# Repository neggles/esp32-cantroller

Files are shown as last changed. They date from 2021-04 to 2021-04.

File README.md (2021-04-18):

# EltekController


This is a little board I whipped up to connect to my [Eltek Flatpack2 Breakout Board](https://github.com/neg2led/EltekFlatpack2) but it should be useful as a general CANBUS control board with wide voltage input.

Most of the parts on the board are outfitted with their LCSC code for KiKit's JLCPCB SMT fab autogeneration. 

I'm using an ESP32-S2-WROOM / ESP32-S2-WROVER module, abusing the on-board USB DFU to avoid having a USB-UART IC.

There's a header designed to take a cheap AliExpress 1.3" 128x64 OLED module, a Qwiic connector for... reasons? and a footprint that matches ESP-Prog pinout and works with:

- Any 2x3 1.27mm IDC header, shrouded or unshrouded, or appropriate pogopin matrix
- Tag-Connect TC2030-NL programming pogopin connector
- Harwin Gecko 1.25mm pitch wire-to-board connector

There's probably some other stuff that'll fit just fine as well.

The DC-DC converter module is a fancy TDK-Lambda one which I got a whole bunch of from Digikey's Chip Outpost for like 20c each, when I run out I'll probably make another version using either an on-board converter or another module, one that outputs 5V so the Qwiic connector is actually in-spec and the XC6220 isn't solely used for USB-bus-powered mode.

To be honest, expect to see the on-board DC-DC version soon, because this module is C H O N K Y.

I've probably made some really bad design choices here, please don't judge me.

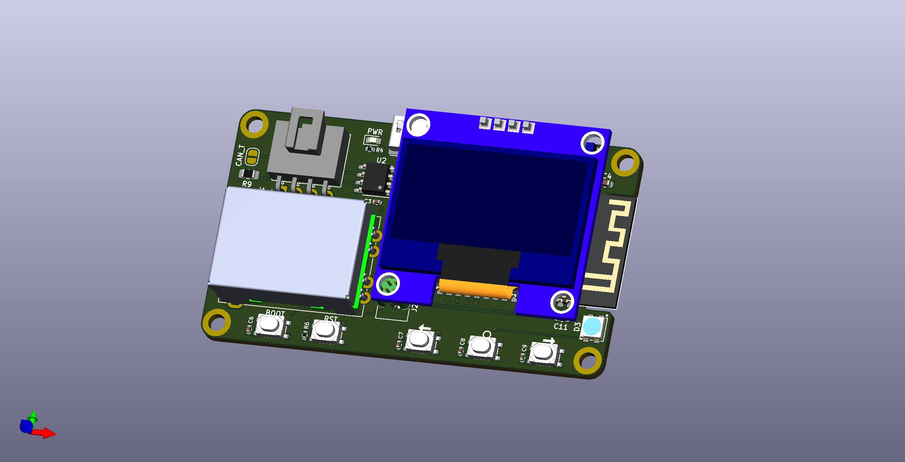
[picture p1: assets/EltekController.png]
KiCad raytraced board render


## Repository Structure
- `EltekController` contains the main schematics and board drawing
- `EltekController/EltekController.pretty` contains the board-specific footprints
- `EltekController/shapes3D` contains the 3D models for parts on the board (and a bunch of extras from my various experiments)

## Building
Simply call `make` in the top-top level directory. The `build` directory will then contain:

- the main board
- A panelized version of said board
- zipped gerbers for the boards you can directly use for manufacturing
- zipped gerbers and SMT assembly BOM/position files for JLCPCB's SMT assembly service for the single-board version.

Makefile uses [Jan Mrázek](https://github.com/yaqwsx)'s [KiKit](https://github.com/yaqwsx/KiKit), which I cannot recommend enough, and therefore has to be available on your system.

Jan's [jlcparts](https://yaqwsx.github.io/jlcparts/) app was also extremely useful in narrowing down part choices based on what JLCPCB have available.

-----
### **IMPORTANT NOTE:** If you give JLCPCB these files as-is, *please* verify the orientation of every part before submitting.

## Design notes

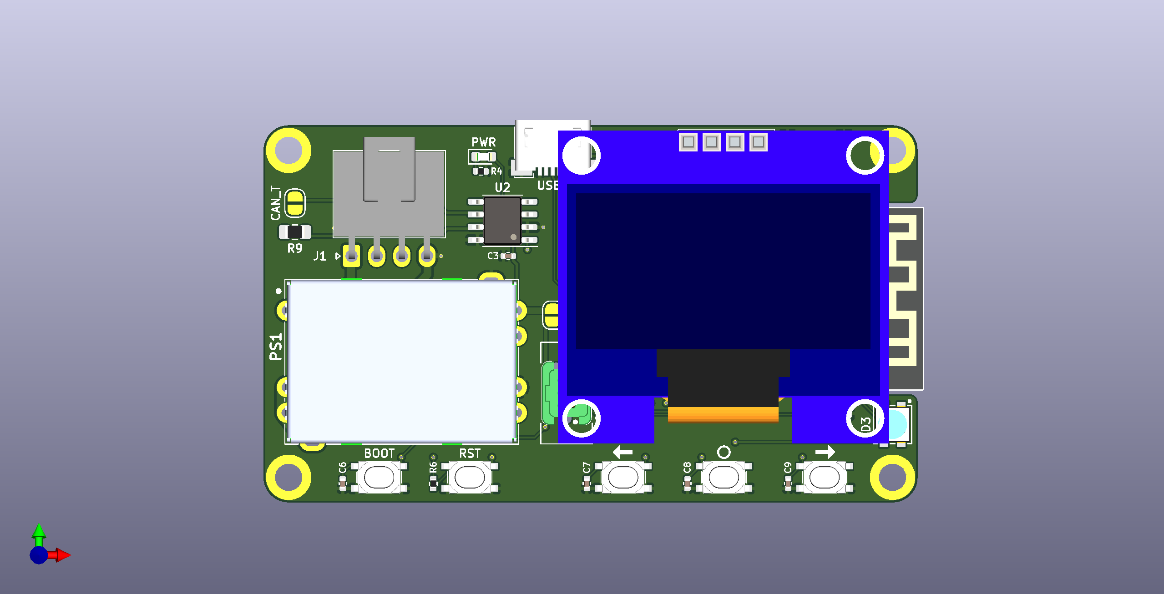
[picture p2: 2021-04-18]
assets/EltekController-top.png

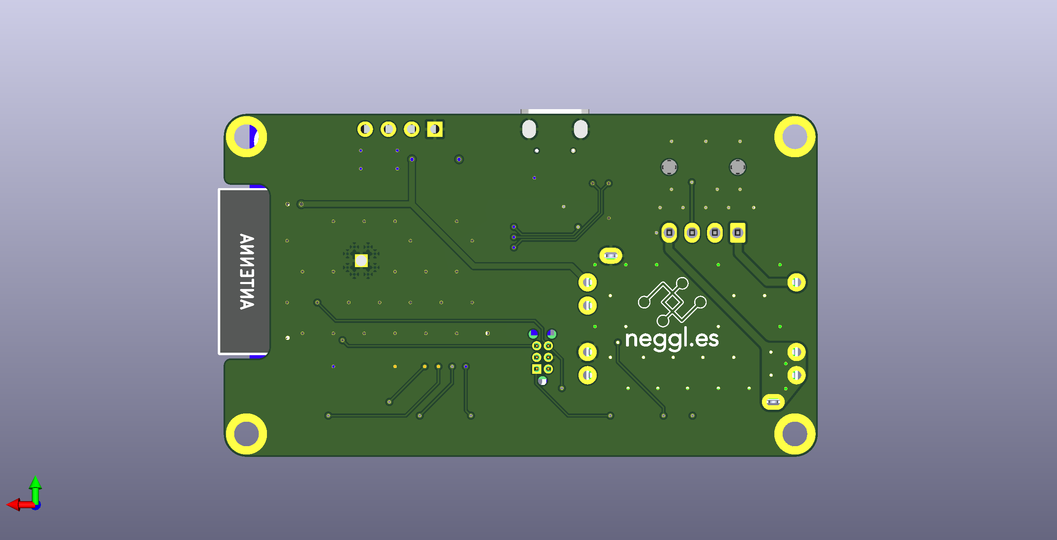
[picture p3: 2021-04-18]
assets/EltekController-bottom.png

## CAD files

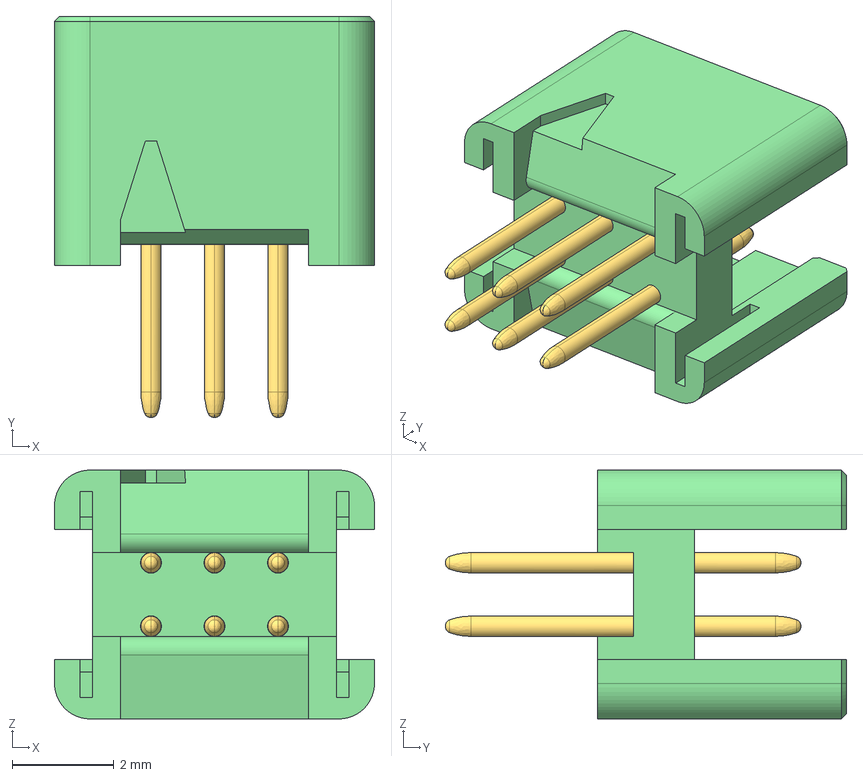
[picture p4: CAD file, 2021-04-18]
EltekController/shapes3D/g125-mv10605l0_asm.stp
6.30 x 7.90 x 4.90 mm
G125-3010696
G125-1030005 x 6

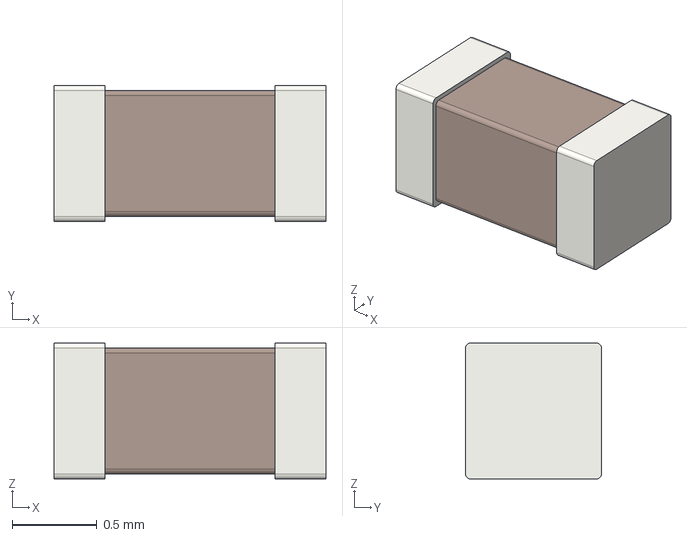
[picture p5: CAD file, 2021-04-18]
EltekController/shapes3D/C_0603_1608Metric.step
1.60 x 0.8 x 0.8 mm

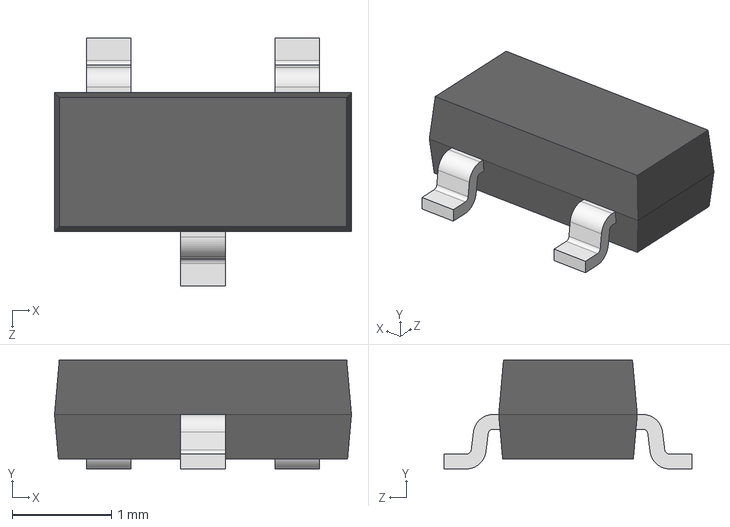
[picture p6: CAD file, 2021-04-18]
EltekController/shapes3D/SOT-23.step
3.00 x 1.10 x 2.50 mm

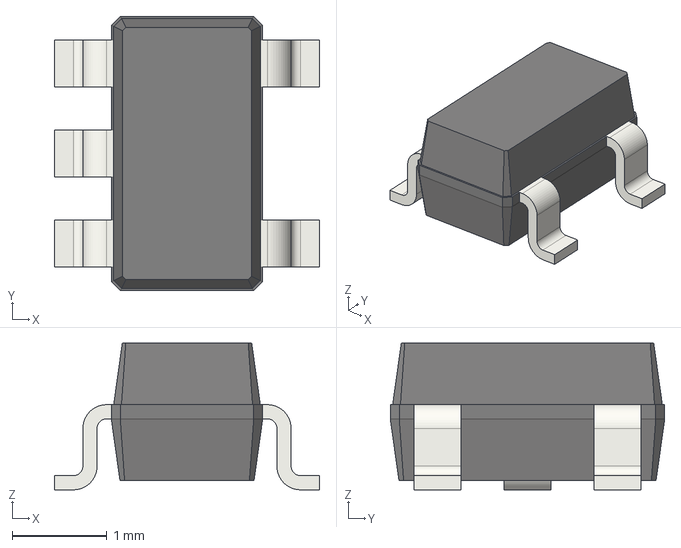
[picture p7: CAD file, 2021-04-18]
EltekController/shapes3D/SOT-23-5.step
2.80 x 2.90 x 1.55 mm

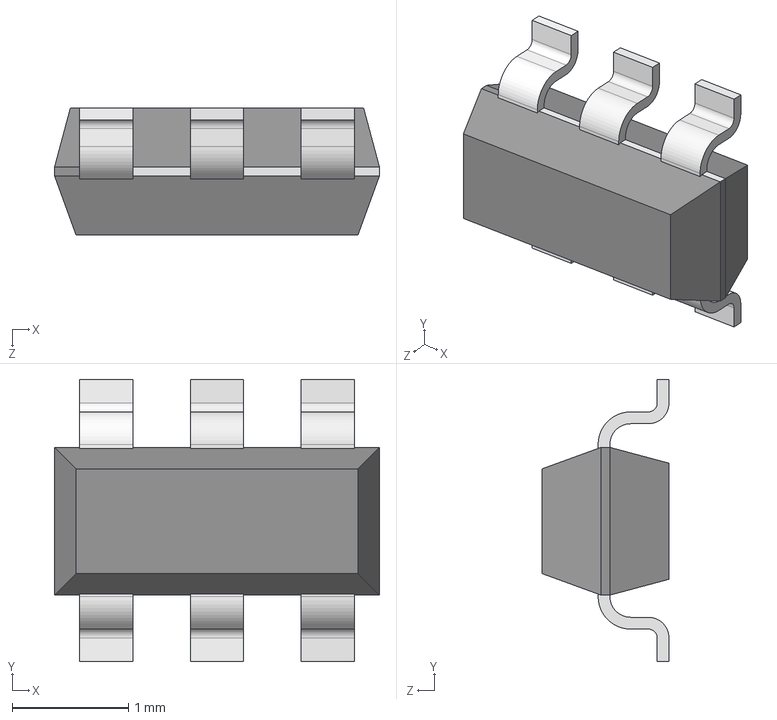
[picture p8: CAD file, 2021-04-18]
EltekController/shapes3D/SOT-23-6.step
2.79 x 2.43 x 1.09 mm

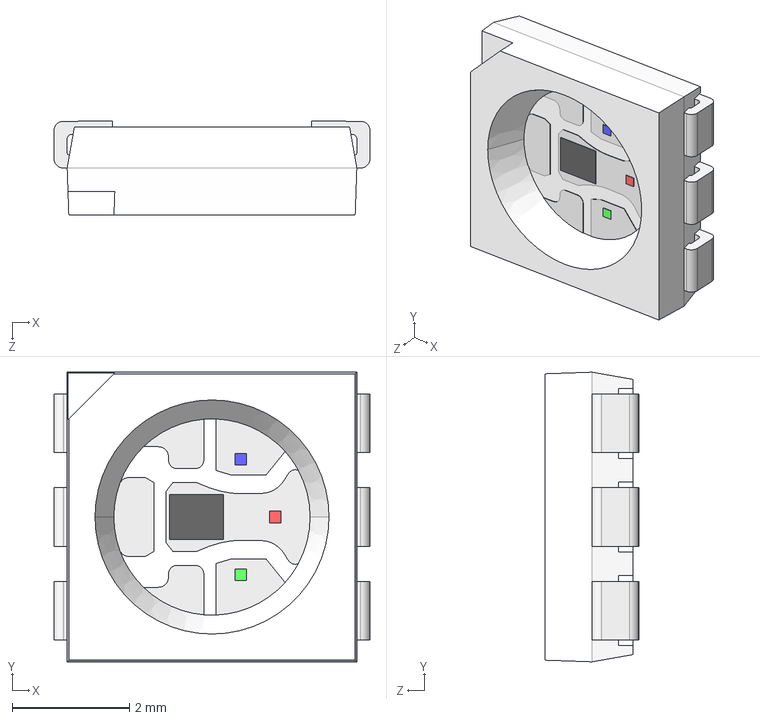
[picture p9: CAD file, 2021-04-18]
EltekController/shapes3D/WS2812S.STEP
5.40 x 4.95 x 1.60 mm

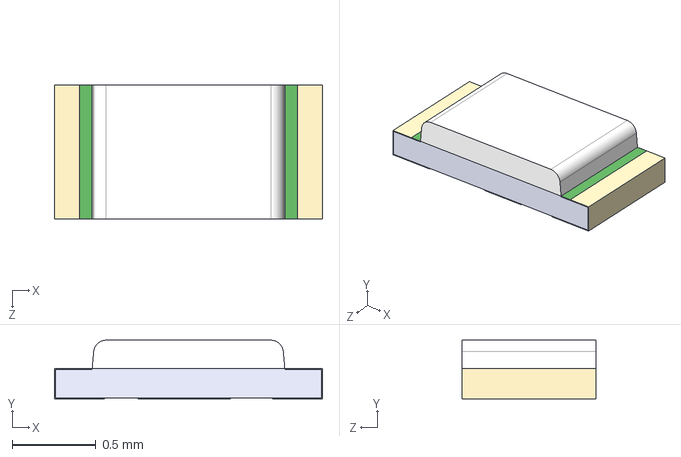
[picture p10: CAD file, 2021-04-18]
EltekController/shapes3D/LTST-C193TBKT-5A.step
1.60 x 0.35 x 0.8 mm

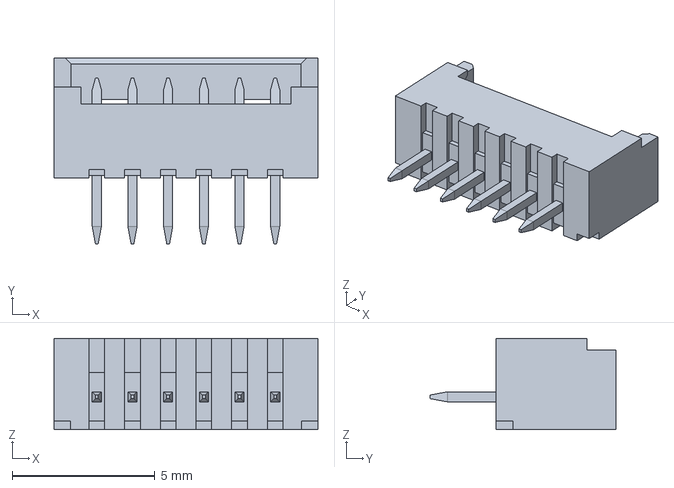
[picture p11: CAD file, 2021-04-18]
EltekController/shapes3D/WU06S-Molex_PicoBlade_530470610_1x06_P1.25mm_Vertical.step
9.25 x 6.50 x 3.20 mm

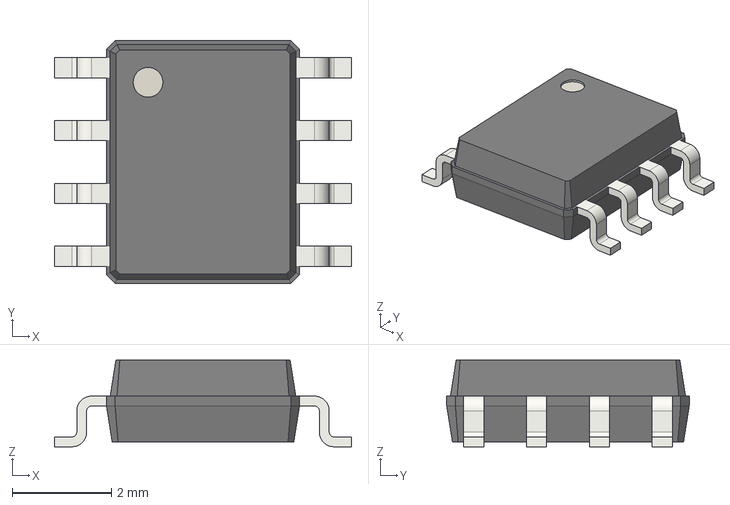
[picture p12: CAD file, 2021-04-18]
EltekController/shapes3D/SOIC-8_3.9x4.9mm_P1.27mm.step
6.00 x 4.90 x 1.75 mm

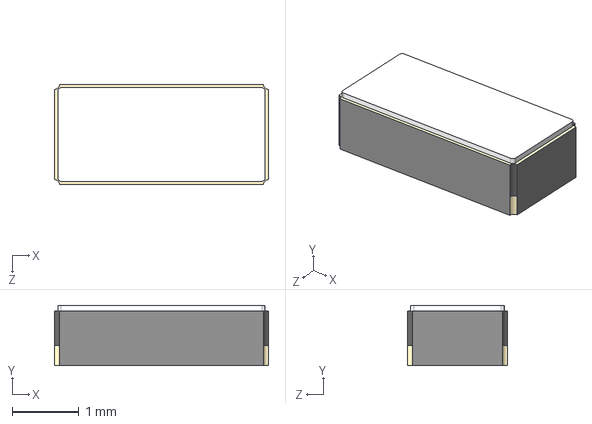
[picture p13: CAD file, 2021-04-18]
EltekController/shapes3D/Q32.768kHz_12.5pF_2P_SMD1206---ECS-.327-12.5-34B-C-TR.STEP
3.20 x 0.9 x 1.50 mm

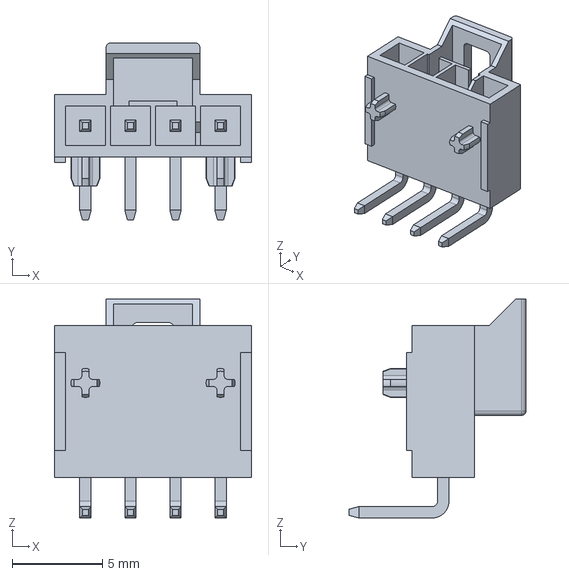
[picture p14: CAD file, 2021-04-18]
EltekController/shapes3D/Molex_Nano-Fit_105313-xx04_1x04_P2.50mm_PTH_Clips_Horz.step
10.9 x 9.84 x 12.2 mm

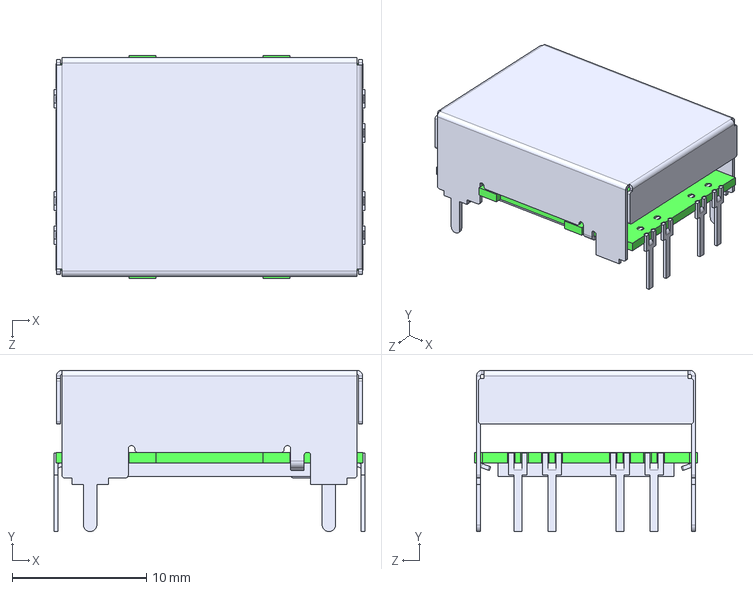
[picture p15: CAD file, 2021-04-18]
EltekController/shapes3D/cc3-f-e_outline.step
23.2 x 12.0 x 16.6 mm

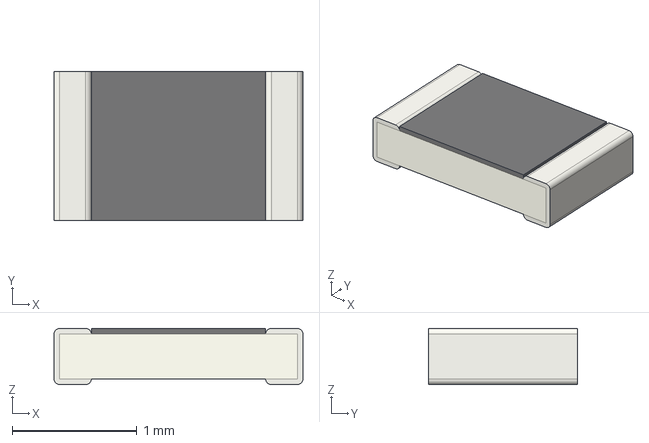
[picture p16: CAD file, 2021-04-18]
EltekController/shapes3D/R_0805_2012Metric.step
2.00 x 1.20 x 0.45 mm

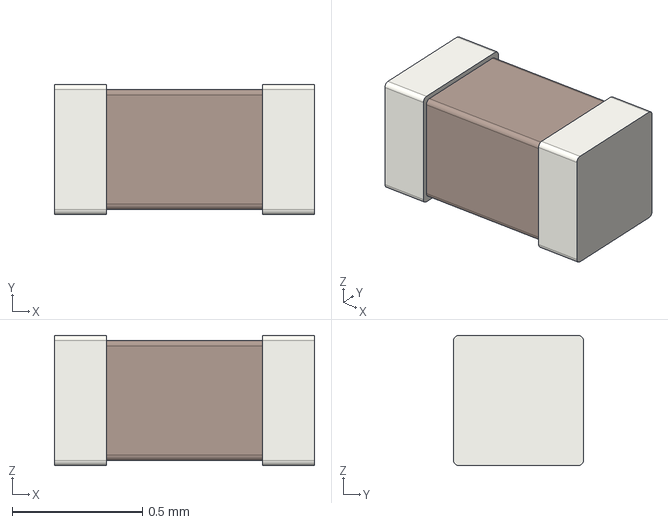
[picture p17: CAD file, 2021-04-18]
EltekController/shapes3D/C_0402_1005Metric.step
1.00 x 0.5 x 0.5 mm

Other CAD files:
EltekController/shapes3D/ESP32-S2-WROVER-I.STEP
EltekController/shapes3D/OLED_1.3.STEP
EltekController/shapes3D/R_0402_1005Metric.step
EltekController/shapes3D/SM04B-SRSS-TB.STEP
EltekController/shapes3D/CON_TE_5-103634-3.stp
EltekController/shapes3D/SHF-103-01-L-D-TH.stp
EltekController/shapes3D/SMD3535 RGB.stp
EltekController/shapes3D/SOD123.step
EltekController/shapes3D/SOT-89.step

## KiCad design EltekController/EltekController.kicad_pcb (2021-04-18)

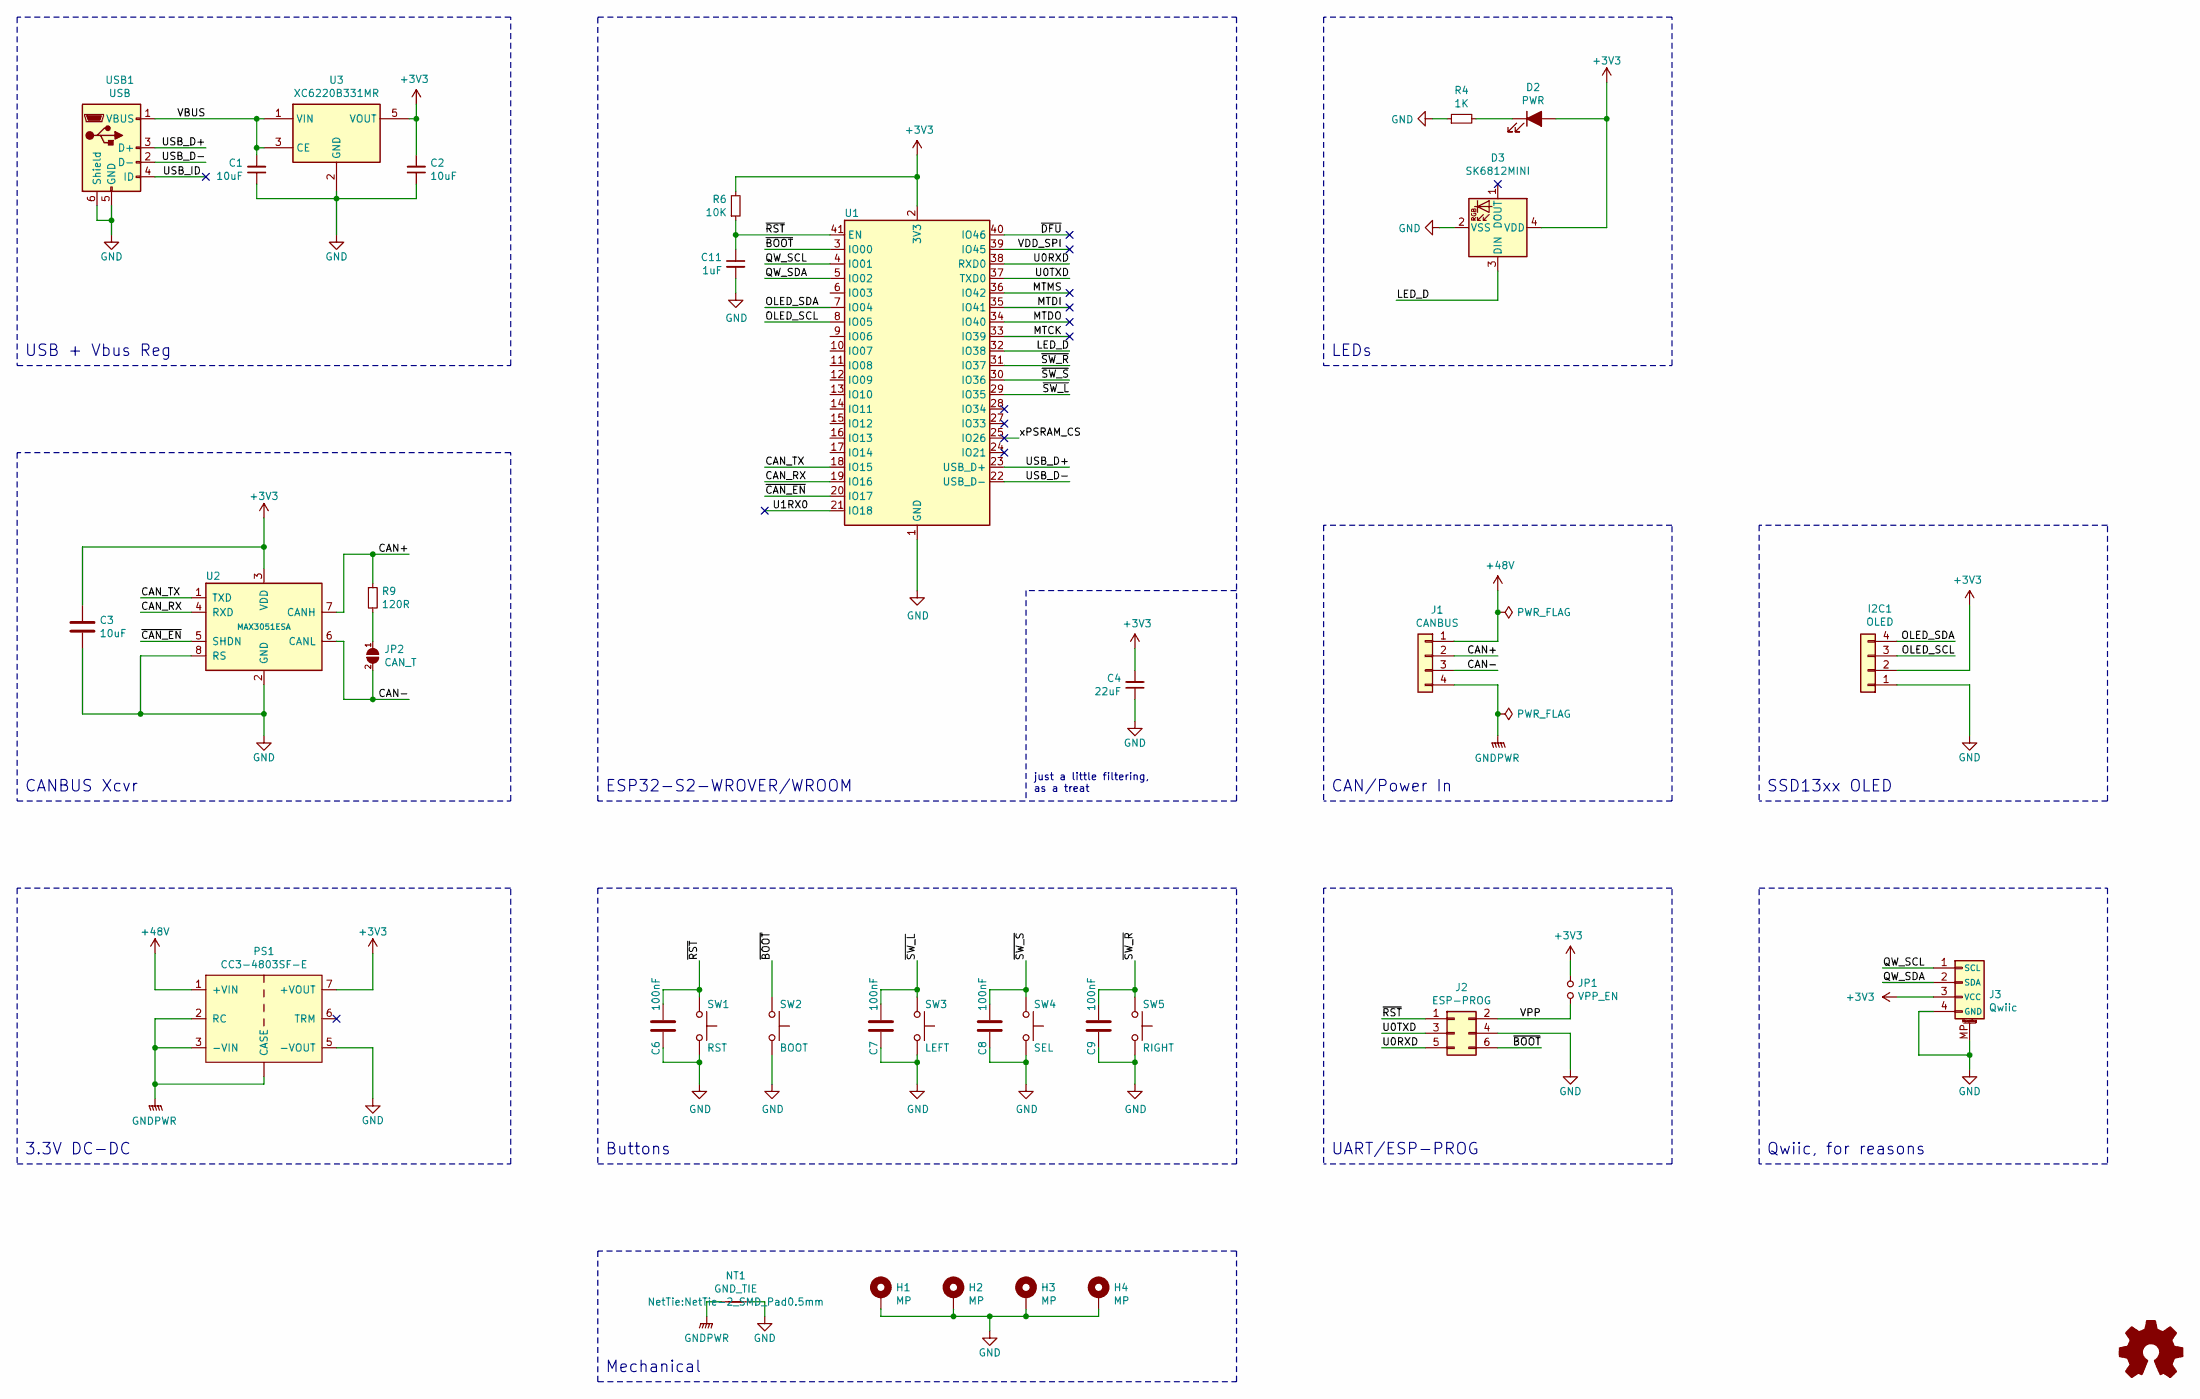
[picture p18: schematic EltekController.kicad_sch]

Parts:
C1, C2, C3: 10uF; C_0402_1005Metric; MPN CL05A106MQ5NUNC; LCSC C15525
C4: 22uF; C_0603_1608Metric; MPN CL10A226MQ8NRNC; LCSC C59461
C6, C7, C8, C9: 100nF; C_0402_1005Metric; MPN CL05B104KO5NNNC; LCSC C1525
C11: 1uF; C_0402_1005Metric; MPN CL05A105KA5NQNC; LCSC C52923
D2: PWR; LED_0603_1608Metric_SnapModel; MPN 19-217/GHC-YR1S2/3T; LCSC C72043
D3: SK6812MINI; LED_SK6812MINI_PLCC4_3.5x3.5mm_P1.75mm_3D
H1, H2, H3, H4: MP; MountingHole_2.7mm_M2.5_ISO7380_Pad_TopBottom
I2C1: OLED; OLED_SSD1315_128x64_1.3_I2C_New_Silhouette_Big3D
J1: CANBUS; Molex_Nano-Fit_105313-xx04_1x04_P2.50mm_Horizontal_3D
J2: ESP-PROG; Gecko-G125_PlusTC2030_IDCBox_2x03_P1.25mm_Vertical_3D
J3: Qwiic; JST_SH_SM04B-SRSS-TB_1x04-1MP_P1.00mm_Horizontal_3D
JP1: VPP_EN; SolderJumper-2_P1.3mm_Open_RoundedPad1.0x1.5mm
JP2: CAN_T; SolderJumper-2_P1.3mm_Open_RoundedPad1.0x1.5mm
LOGO1: Logo_Open_Hardware_Small; neggle-logo-0.12
NT1: GND_TIE; NetTie-2_SMD_Pad0.5mm
PS1: CC3-4803SF-E; Converter_DCDC_TDK-Lambda_CC3-xxxxxF-E
R4: 1K; R_0402_1005Metric; MPN 0402WGF1001TCE; LCSC C11702
R6: 10K; R_0402_1005Metric; MPN 0402WGF1002TCE; LCSC C25744
R9: 120R; R_0805_2012Metric_Pad1.15x1.40mm_HandSolder; MPN 0805W8F1200T5E; LCSC C17437
SW1: RST; KEY-SMD_4P-L4.2-W3.2-P2.20-LS5.1-TL; MPN K2-1808SN-A4SW-01; LCSC C92589
SW2: BOOT; KEY-SMD_4P-L4.2-W3.2-P2.20-LS5.1-TL; MPN K2-1808SN-A4SW-01; LCSC C92589
SW3: LEFT; KEY-SMD_4P-L4.2-W3.2-P2.20-LS5.1-TL; MPN K2-1808SN-A4SW-01; LCSC C92589
SW4: SEL; KEY-SMD_4P-L4.2-W3.2-P2.20-LS5.1-TL; MPN K2-1808SN-A4SW-01; LCSC C92589
SW5: RIGHT; KEY-SMD_4P-L4.2-W3.2-P2.20-LS5.1-TL; MPN K2-1808SN-A4SW-01; LCSC C92589
U1: ESP32-S2-WROVER; ESP32-S2-WROVER_and_WROOM(PCB,-I(IPEX))-Universal; MPN ESP32-S2-WROVER(4MB); LCSC C701333
U2: MAX3051ESA; SOIC-8_3.9x4.9mm_P1.27mm; MPN MAX3051ESA+T; LCSC C15648
U3: XC6220B331MR; SOT-23-5; LCSC C86534
USB1: USB; MICRO-USB-SMD_U254-051T-4BH83-F1S_C397452; LCSC C397452

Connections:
+3V3: C2.2, C3.2, C4.2, D2.2 (A), D3.4 (VDD), I2C1.2, J3.3 (VCC), JP1.1, PS1.7 (+VOUT), R6.2, U1.2 (3V3), U2.3 (VDD), U3.5 (VOUT)
+48V: J1.1, PS1.1 (+VIN)
/CAN+: J1.2, R9.1, U2.7 (CANH)
/CAN-: J1.3, JP2.2 (B), U2.6 (CANL)
/CAN_RX: U1.19 (IO16), U2.4 (RXD)
/CAN_TX: U1.18 (IO15), U2.1 (TXD)
/LED_D: D3.3 (DIN), U1.32 (IO38)
/MTCK: U1.33 (IO39)
/MTDI: U1.35 (IO41)
/MTDO: U1.34 (IO40)
/MTMS: U1.36 (IO42)
/OLED_SCL: I2C1.3, U1.8 (IO05)
/OLED_SDA: I2C1.4, U1.7 (IO04)
/QW_SCL: J3.1 (SCL), U1.4 (IO01)
/QW_SDA: J3.2 (SDA), U1.5 (IO02)
/U0RXD: J2.5, U1.38 (RXD0)
/U0TXD: J2.3, U1.37 (TXD0)
/U1RX0: U1.21 (IO18)
/USB_D+: U1.23 (USB_D+), USB1.3 (D+)
/USB_D-: U1.22 (USB_D-), USB1.2 (D-)
/USB_ID: USB1.4 (ID)
/VBUS: C1.2, U3.1 (VIN), U3.3 (CE), USB1.1 (VBUS)
/VDD_SPI: U1.39 (IO45)
/VPP: J2.2, JP1.2
/xPSRAM_CS: U1.25 (IO26)
/~CAN_EN: U1.20 (IO17), U2.5 (SHDN)
/~DFU: U1.40 (IO46)
/~SW_L: C7.2, SW3.1, U1.29 (IO35)
/~SW_R: C9.2, SW5.1, U1.31 (IO37)
/~SW_S: C8.2, SW4.1, U1.30 (IO36)
GND: C1.1, C2.1, C3.1, C4.1, C6.1, C7.1, C8.1, C9.1, C11.2, D3.2 (VSS), H1.1, H2.1, H3.1, H4.1, I2C1.1, J2.4, J3.4 (GND), J3.MP (MountPin), NT1.2, PS1.5 (-VOUT), PS1.MP2, R4.1, SW1.2, SW2.2, SW3.2, SW4.2, SW5.2, U1.1 (GND), U1.26 (GND), U1.42 (GND), U1.43 (GND), U2.2 (GND), U2.8 (RS), U3.2 (GND), USB1.5 (GND), USB1.6 (Shield)
GNDPWR: J1.4, NT1.1, PS1.2 (RC), PS1.3 (-VIN), PS1.MP (CASE)
unnamed: D2.1 (K), R4.2
unnamed: JP2.1 (A), R9.2

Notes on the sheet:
Qwiic, for reasons
UART/ESP-PROG
CAN/Power In
3.3V DC-DC
Buttons
SSD13xx OLED
ESP32-S2-WROVER/WROOM
Mechanical
just a little filtering, as a treat
CANBUS Xcvr
LEDs
USB + Vbus Reg

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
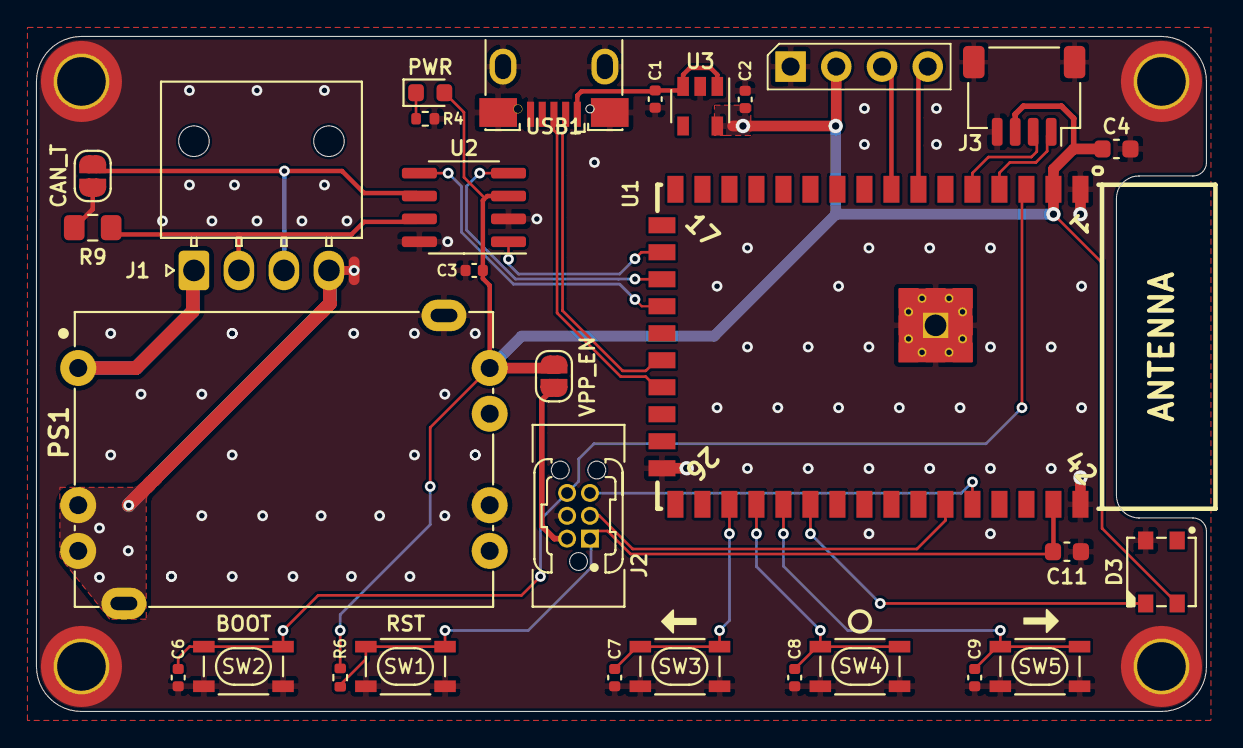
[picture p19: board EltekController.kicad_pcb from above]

Board: 2 copper layers, 65.0 x 37.5 mm, 36 parts (1 on the bottom side), 27 nets.

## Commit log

2021-04-18 initial commit, probably missing some STEPs etc
    [EltekController.16020..sch, EltekController.kicad_pcb, EltekController.sch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]
2021-04-18 update it so the thing kinda works
    [EltekController.16020..sch, EltekController.kicad_pcb, EltekController.sch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]
2021-04-18 Squashed commit of the following:
    commit 90807526c89bbe23d0d14403179393f46968545b
    Author: neg2led <4232981+neg2led@users.noreply.github.com>
    Date: Fri Feb 19 13:40:56 2021 +1100
    change vtabs
    commit bdeb0cb4df280460f20d9cb7594185681e97bdea
    Author: neg2led <4232981+neg2led@users.noreply.github.com>
    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
    [EltekController.kicad_pcb, EltekController.sch, L-CD32_shielded.step]
2021-04-18 fixup ESP32 placement pos
    [EltekController.kicad_pcb, EltekController.sch]
2021-04-18 update, drop firmware folder out for now
    [EltekController.kicad_pcb]
2021-04-18 saving this because I changed my mind again
    [EltekController.kicad_pcb, EltekController.sch]
2021-04-18 yes, good
    [ESP32-S2-WROVER-I.STEP, EltekController.kicad_pcb, EltekController.sch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]
2021-04-18 updoot, new rev
    [EltekController.kicad_pcb, EltekController.sch, SHF-103-01-L-D-TH.stp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]
2021-04-18 add 3d models and internalize footprints
    [CON_TE_5-103634-3.stp, C_0402_1005Metric.step, C_0603_1608Metric.step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]
2021-04-18 oops. update makefile for new board size
2021-04-18 switch to nano-fit, but any 2.54 or 2.5mm header works
    [EltekController.kicad_pcb, EltekController.sch, Molex_Nano-Fit_105313-xx04_1x04_P2.50mm_PTH_Clips_Horz.step]
2021-04-18 missed a trace
    [EltekController.kicad_pcb, EltekController.sch]
2021-04-18 micro-usb footprint fixup
    [EltekController.kicad_pcb]
2021-04-18 flip VCC and GND on the OLED... sigh
    [EltekController.kicad_pcb, EltekController.sch]
2021-04-18 Revert "flip VCC and GND on the OLED... sigh"
    This reverts commit 16d08c3f3e759163bdd9650e3550ba9f731368f2.
    [EltekController.kicad_pcb, EltekController.sch]
2022-11-22 add .gitattributes
    [EltekController.kicad_sch, EltekController.sch]

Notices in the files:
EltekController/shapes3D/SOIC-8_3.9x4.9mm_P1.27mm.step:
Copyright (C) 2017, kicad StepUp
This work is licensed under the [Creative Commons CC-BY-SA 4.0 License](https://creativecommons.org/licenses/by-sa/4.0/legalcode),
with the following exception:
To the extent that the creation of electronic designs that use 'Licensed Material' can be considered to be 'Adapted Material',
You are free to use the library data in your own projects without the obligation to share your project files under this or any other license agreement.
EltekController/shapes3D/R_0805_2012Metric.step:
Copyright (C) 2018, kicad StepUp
